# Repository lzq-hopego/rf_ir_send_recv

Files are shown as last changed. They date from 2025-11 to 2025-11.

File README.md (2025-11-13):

## 项目简介
**基于ESP8266的射频和红外网关**
1. 使用ESP8266-12F模组制作射频和红外网关
2. 可对433/315非加密射频信号学习与发送
3. 可对红外信息进行学习和发送
4. 因为作者~~太懒~~(想打造互联生态)所以有了本项目
> 使得以上设备可通过移动端设备进行远程控制

## 打板子注意事项
1. 板厚：**1.2mm**

## 项目架构
```mermaid
graph LR
C{MQTT服务器}
C <-.8083端口.-> D[手机端]
C <-.1883端口.-> E[ESP8266]

```

所有数据围绕着MQTT服务器进行的，因此你需要自己搭建一个MQTT服务器或者使用现成的MQTT服务器
### MQTT服务器架设
> 建议使用docker进行搭建，我们选择**emqx**

```shell
docker run -d --name emqx \
  -p 1883:1883 -p 8083:8083 -p 8084:8084 \
  -p 8883:8883 -p 18083:18083 \
  emqx/emqx-enterprise:latest
```
- 想静静一会就自动部署好啦🎈
- 如果是Linux记得放行端口呦
> EMQX的默认用户名是`admin`,默认密码`public`,web端口默认是`18083`

## 项目功能
> 本项目具有`自学习`，`远程控制`等特点

1. 具有测量实时温湿度功能。
2. 具有433/315信号学习。
3. 具有模拟433/315信号发送。
4. 具有红外信号学习。
5. 具有红外信号发送功能。
6. 具有指示灯。
7. 具有可重置设备的按钮。
8. 具有手机端控制功能。
9. 具有web配网

## 项目方案

1. 使用ESP8266连接路由器后建立MQTT连接实现设备上云。
2. 使用蜂鸟无线 `远-R1`实现433/315信号学习。
3. 使用蜂鸟无线 `远-T1`实现433/315信号发送。
4. 使用`IRM-3638T` 实现红外接收。
5. 使用某宝不知名品牌的`红外发射管` 实现红外发射。
6. 使用`SHT30-DIS-B10KS` 实现实时温湿度测量。

```mermaid
graph LR
C((指示灯))
C -.卡针单戳按钮.-> D[重启 指示灯闪烁2次]
C -.卡针长按按钮.-> E[配置清空 指示灯长亮3次]
C -.接收/发送射频信号.-> F[指示灯短亮1次]
C -.连接上WiFi.-> G[指示灯短亮3次]
```
> 使用手机卡针戳type-c旁的圆孔即可实现上图1、2的操作

## 项目说明
> 简化电路
射频电路参考[RF 433 315射频网关盒子](https://oshwhub.com/yanqisui/rf-433-315-she-pin-wang-guan-he-zi)这个项目，他有说天线的问题
1. 关于天线可以都不焊接，射频接收可直接焊接0欧电阻使用板载天线，射频发射可以直接不焊接任何电阻天线之类的，因为测试过程中生活中的射频接收反而很敏感无需再焊接天线
2. 电路中的type-c旁的`二极管`可以不用焊接直接一坨锡或者0欧电阻或者直接在电路中删去
3. `AMS1117 3.3`后面的钽电容如果想省略也可直接不焊接
4. 电路板左上方的重启按钮也可省略(不是type-c旁边的那个侧贴的按钮，如果不需要物理重置功能也可以删掉，反正WiFi连接失败后会自动让你重新配网)

## 项目源码
1. 手机端APP——uni-app构建      已打包见附件
2. ESP8266端——Arduino          已编译见附件

如果自行编译ESP8266端固件需要修改`PubSubClient`库的`PubSubClient.h`源码
```cpp
#define MQTT_MAX_PACKET_SIZE 4096
```
> 因为我们的很大，它自己默认的太小了，给它~~撑大~~改一点

## 关于外壳
- 外壳是自己画的不太好看，爆炸图效果如下，但是满足嘉立创3D免费打印条件，直接~~白嫖~~免费

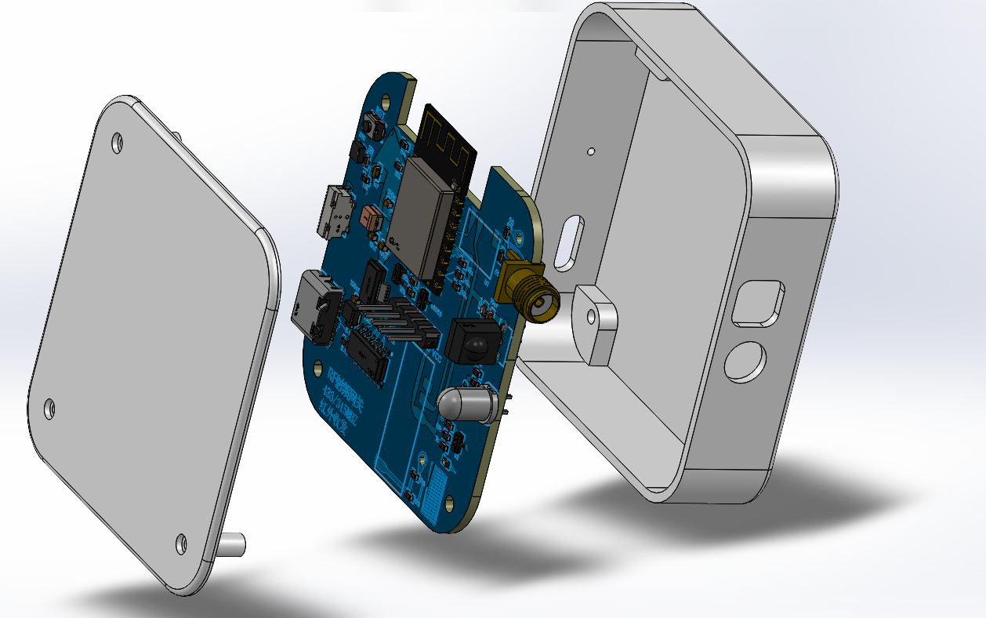
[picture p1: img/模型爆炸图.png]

- 螺丝M1.6*14mm
- 螺母滚花铜螺母M1.6\*3\*2.5

## 效果图
- ESP8266配置页效果图

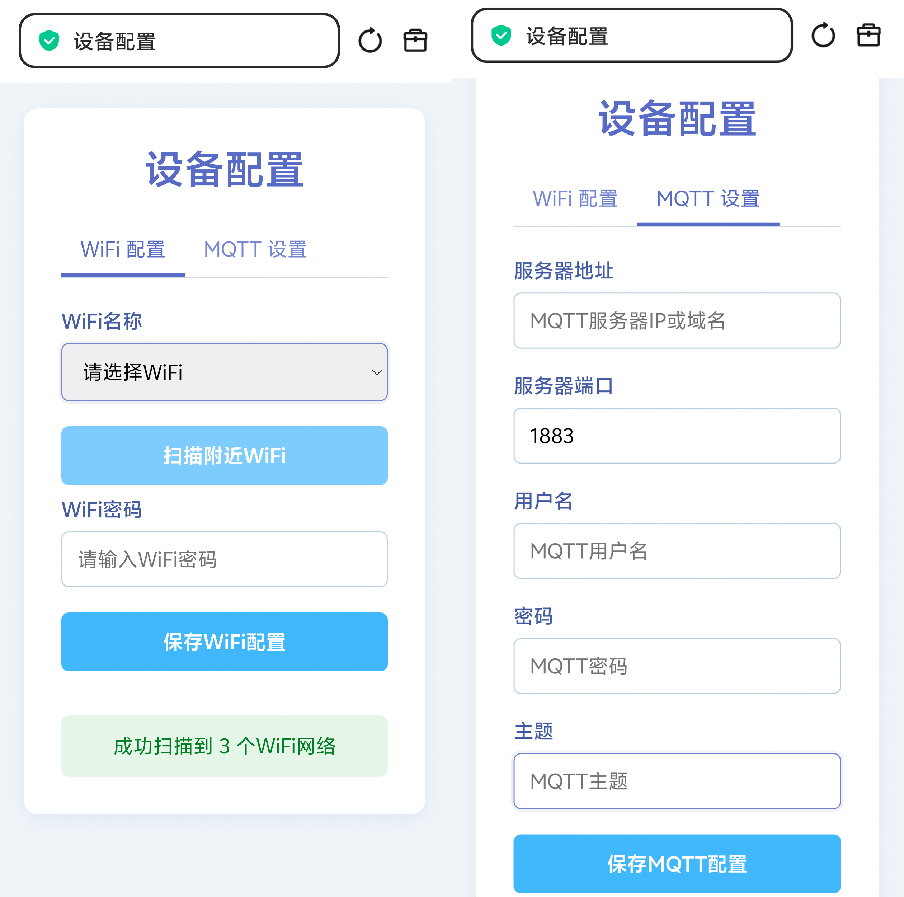
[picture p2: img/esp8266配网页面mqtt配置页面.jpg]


> 这里的服务器端口建议用默认的1883端口，MQTT主题要和软件的主题配置一致，同时建议使用用户名密码方式验证，你可以在EMQX中创建认证数据库时选择这一项

- 手机端效果图

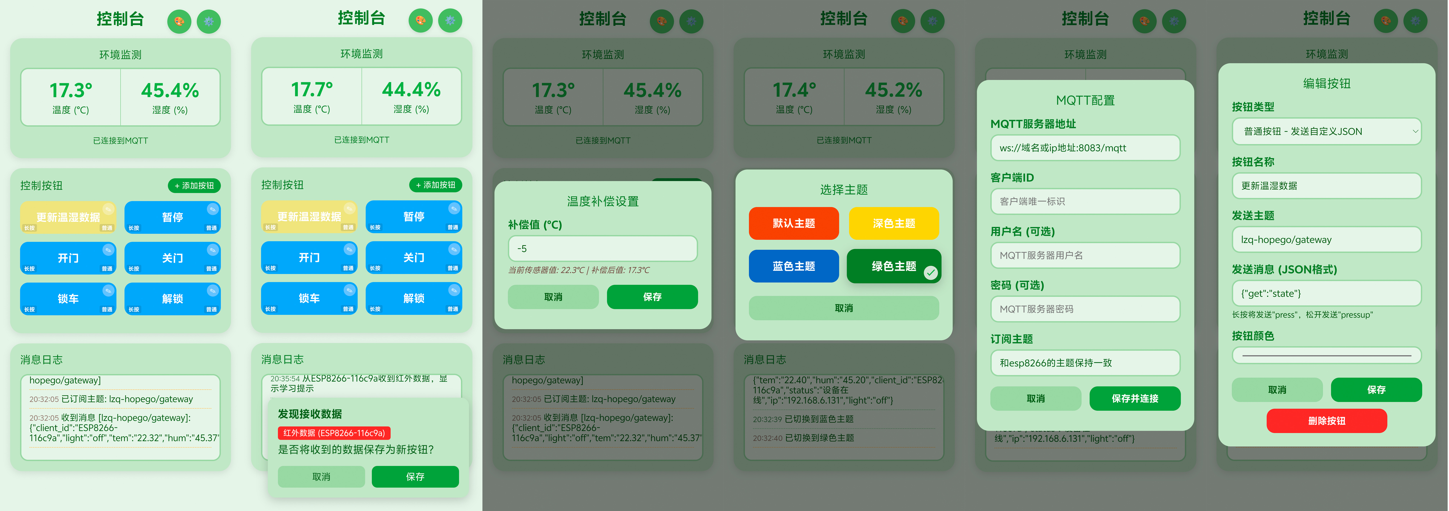
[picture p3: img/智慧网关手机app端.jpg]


> 注意MQTT配置的主题和ESP8266配置的主题一致即可

- 焊接成品图



## 开源声明
1. 本工具仅用于个人学习与研究，禁止任何商业用途（包括但不限于盈利性服务、企业内部使用等）
2. 不得以任何形式任何途径出售本项目提供的固件、软件、以及代码等相关资料
3. 若发现侵权或违规使用情况，请通过维护者邮箱联系，会在 3 个工作日内处理
4. 除去上述要求外，还需遵守本项目的开源协议

## 致谢
> 在以下项目中获得了本项目的灵感
1. [RF 433 315射频网关盒子](https://oshwhub.com/yanqisui/rf-433-315-she-pin-wang-guan-he-zi)
2. [墨水屏阅读器](https://oshwhub.com/jie326513988/SDka-mo-shui-ping-yue-du-qi)
3. [涂鸦_红外](https://oshwhub.com/pppw/tu-ya_-hong-wai)

## 项目信息
- 项目创建者：李先生
- 项目维护者：李先生
- 维护者邮箱：3101978435@qq.com

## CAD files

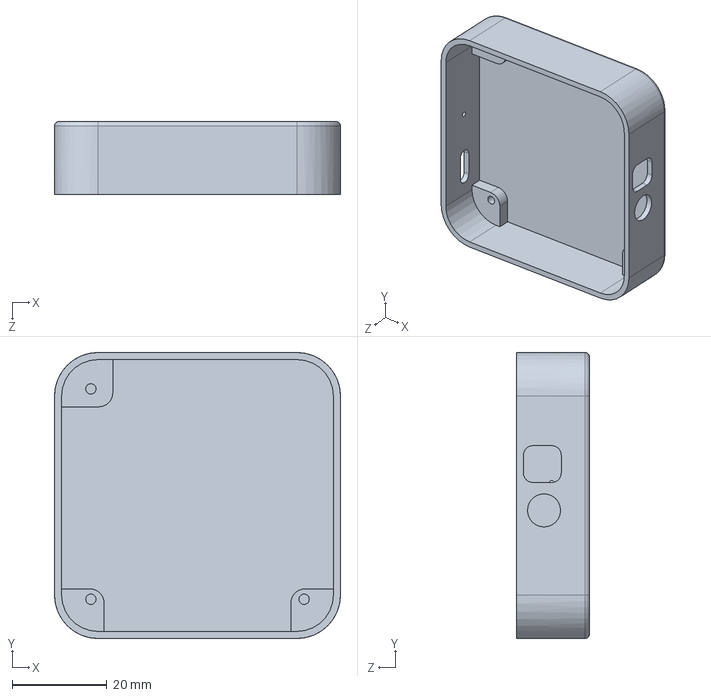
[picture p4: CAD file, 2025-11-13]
3D打印文件/底壳.SLDPRT
60.5 x 60.5 x 15.5 mm

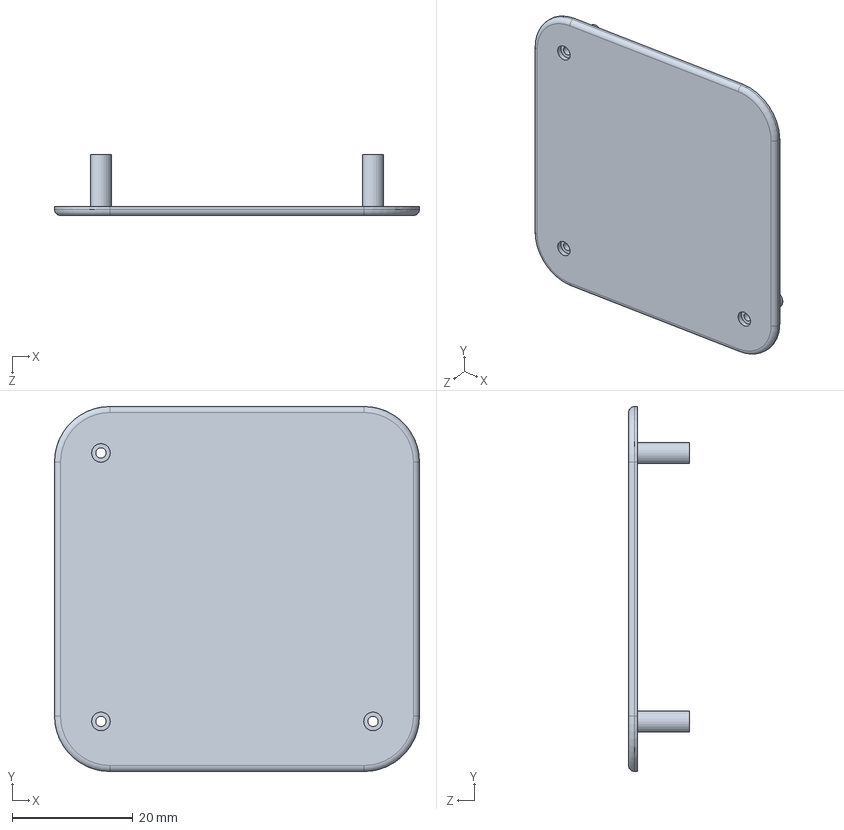
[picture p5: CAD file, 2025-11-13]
3D打印文件/上盖.SLDPRT
60.5 x 60.5 x 10.1 mm

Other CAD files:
3D打印文件/上盖.STL
3D打印文件/底壳.STL

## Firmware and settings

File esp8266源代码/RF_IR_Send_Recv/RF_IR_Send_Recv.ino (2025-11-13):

#include <ESP8266WiFi.h>
#include <ESP8266WebServer.h>
#include <Arduino.h>
#include <EEPROM.h>
#include <ArduinoJson.h>
#include <PubSubClient.h>
#include <RCSwitch.h>
#include <Wire.h>
#include <IRrecv.h>
#include <IRremoteESP8266.h>
#include <IRsend.h>
#include <IRutils.h>
#include "ClosedCube_SHT31D.h"
#include <OneButton.h>  // 引入OneButton库


// 智能网关v1.0.1
// 作者:lzq-hopego
// 最后保存时间:2025年11月12日 21点33分
// 关于代码版权问题，再次开源时需标注原作者，不得商业化，除此之外还需遵守MIT协议


// 配置存储地址和大小
#define EEPROM_SIZE 512
#define CONFIG_ADDR 0          
#define WIFI_ADDR CONFIG_ADDR
#define MQTT_ADDR sizeof(ConfigWiFi)

// 引脚定义（根据硬件调整）
#define BUTTON_PIN 12    // 按钮引脚（一端接IO12，另一端接地）
#define INDICATOR_PIN 15 // 指示灯引脚（高电平点亮）
// 433/315
const int rcsPin = 5; //433发射模块
const int rcrPin = 4; //433接收模块
// 红外接收配置参数
const uint16_t kRecvPin = 0;        // 红外接收引脚（如D3）
const uint32_t kBaudRate = 115200;  // 串口波特率
const uint16_t kCaptureBufferSize = 1024;
const uint8_t kTimeout = 50;        // 信号超时时间（毫秒）
// 红外发射配置参数
const uint16_t kIrLed = D0;

// 全局对象（按钮初始化修改）
RCSwitch mySwitchSend = RCSwitch();
RCSwitch mySwitchRecv = RCSwitch();
ClosedCube_SHT31D sht3xd;
IRrecv irrecv(kRecvPin, kCaptureBufferSize, kTimeout, true);
decode_results results;
IRsend irsend(kIrLed);
// 按钮初始化：禁用内部上拉（因为按钮接GND，按下时为低电平）
OneButton button(BUTTON_PIN);  // 第二个参数改为false（禁用内部上拉）
// 板载LED配置（IO2，低电平点亮）
#define LED_PIN 2
bool ledState = false;  // 记录LED当前状态：false=灭，true=亮

// 配置结构体（保持不变）
struct ConfigWiFi {
  char ssid[32];
  char password[32];
};
struct ConfigMQTT {
  char server[40];
  char port[6];
  char user[32];
  char pass[32];
  char topic[64];
};

// 全局变量（保持不变）
ConfigWiFi configWiFi;
ConfigMQTT configMQTT;
bool mqttUnconfigured = false;  // 控制MQTT未配置提示只显示一次
ESP8266WebServer server(80);
WiFiClient espClient;
PubSubClient mqttClient(espClient);
int reconnectAttempts = 0;
int mqttReconnectAttempts = 0;
String clientId;  // 保存唯一客户端ID用于过滤消息
// AP模式关键参数
const char* apPassword = "12345678";
const int apChannel = 6;
const bool apHidden = false;
const int apMaxConn = 3;
// HTML页面内容（保持不变）
const char index_html[] PROGMEM = R"rawliteral(
<!DOCTYPE html>
<html>
<head>
    <meta charset="UTF-8">
    <meta name="viewport" content="width=device-width, initial-scale=1.0">
    <title>设备配置</title>
    <style>
        * { box-sizing: border-box; margin: 0; padding: 0; }
        body { 
            font-family: 'Arial', sans-serif; 
            max-width: 500px; 
            margin: 0 auto; 
            padding: 20px; 
            background: #f0f4f8; 
            color: #3a4a5c;
        }
        .container { 
            background: white; 
            padding: 30px; 
            border-radius: 12px; 
            box-shadow: 0 4px 15px rgba(100, 120, 180, 0.1);
        }
        h1 { 
            color: #5c6bc0; 
            margin-bottom: 25px; 
            text-align: center;
            font-weight: 600;
        }
        .form-group { 
            margin-bottom: 20px; 
        }
        label { 
            display: block; 
            margin-bottom: 8px; 
            font-weight: 500;
            color: #4a5ca0;
        }
        input, select { 
            width: 100%; 
            padding: 12px; 
            border: 1px solid #bdd0e0; 
            border-radius: 6px; 
            font-size: 16px;
            transition: border 0.3s;
        }
        input:focus, select:focus { 
            border-color: #7986cb; 
            outline: none; 
            box-shadow: 0 0 0 2px rgba(100, 120, 180, 0.1);
        }
        button { 
            width: 100%; 
            padding: 14px; 
            background: #64b5f6; 
            color: white; 
            border: none; 
            border-radius: 6px; 
            font-size: 16px; 
            font-weight: 600; 
            cursor: pointer;
            transition: background 0.3s;
            margin-bottom: 15px;
        }
        button:hover { 
            background: #42a5f5; 
        }
        .scan-btn {
            background: #90caf9;
            margin-bottom: 10px;
        }
        .scan-btn:hover {
            background: #64b5f6;
        }
        .status {
            margin-top: 20px;
            padding: 15px;
            border-radius: 6px;
            display: none;
            text-align: center;
        }
        .success {
            background: #e8f5e9;
            color: #2e7d32;
            display: block;
        }
        .error {
            background: #ffebee;
            color: #c62828;
            display: block;
        }
        .tab-content {
            display: none;
        }
        .tab-content.active {
            display: block;
        }
        .nav-tabs {
            display: flex;
            margin-bottom: 25px;
            border-bottom: 1px solid #d1d9e6;
        }
        .nav-tab {
            padding: 10px 15px;
            cursor: pointer;
            color: #7986cb;
            border-bottom: 3px solid transparent;
            transition: all 0.3s;
        }
        .nav-tab.active {
            color: #5c6bc0;
            border-bottom: 3px solid #5c6bc0;
        }
        .nav-tab:hover {
            color: #5c6bc0;
        }
        .loading {
            text-align: center;
            color: #5c6bc0;
            padding: 10px;
            display: none;
        }
    </style>
</head>
<body>
    <div class="container">
        <h1>设备配置</h1>
        <div class="nav-tabs">
            <div class="nav-tab active" onclick="showTab('wifi-tab')">WiFi 配置</div>
            <div class="nav-tab" onclick="showTab('mqtt-tab')">MQTT 设置</div>
        </div>
        <div id="wifi-tab" class="tab-content active">
            <div class="form-group">
                <label for="ssid">WiFi名称</label>
                <select id="ssid" required>
                    <option value="">请选择WiFi</option>
                </select>
            </div>
            <button class="scan-btn" onclick="scanWiFi()">扫描附近WiFi</button>
            <div class="loading" id="wifi-loading">正在扫描WiFi...</div>
            <div class="form-group">
                <label for="wifi_password">WiFi密码</label>
                <input type="password" id="wifi_password" placeholder="请输入WiFi密码">
            </div>
            <button onclick="saveWiFiConfig()">保存WiFi配置</button>
        </div>
        <div id="mqtt-tab" class="tab-content">
            <div class="form-group">
                <label for="mqtt_server">服务器地址</label>
                <input type="text" id="mqtt_server" placeholder="MQTT服务器IP或域名" required>
            </div>
            <div class="form-group">
                <label for="mqtt_port">服务器端口</label>
                <input type="number" id="mqtt_port" value="1883" required>
            </div>
            <div class="form-group">
                <label for="mqtt_user">用户名</label>
                <input type="text" id="mqtt_user" placeholder="MQTT用户名">
            </div>
            <div class="form-group">
                <label for="mqtt_pass">密码</label>
                <input type="password" id="mqtt_pass" placeholder="MQTT密码">
            </div>
            <div class="form-group">
                <label for="mqtt_topic">主题</label>
                <input type="text" id="mqtt_topic" placeholder="MQTT主题" required>
            </div>
            <button onclick="saveMQTTConfig()">保存MQTT配置</button>
        </div>
        <div id="status" class="status"></div>
    </div>
    <script>
        function showTab(tabId) {
            document.querySelectorAll('.tab-content').forEach(tab => tab.classList.remove('active'));
            document.querySelectorAll('.nav-tab').forEach(nav => nav.classList.remove('active'));
            document.getElementById(tabId).classList.add('active');
            document.querySelector(`.nav-tab[onclick="showTab('${tabId}')"]`).classList.add('active');
        }
        function scanWiFi() {
          document.getElementById('wifi-loading').style.display = 'block';
          fetch('/scanWiFi')
            .then(response => {
              if (!response.ok) {
                throw new Error(`HTTP错误：${response.status}`);
              }
              return response.json();
            })
            .then(networks => {
              const ssidSelect = document.getElementById('ssid');
              while (ssidSelect.options.length > 1) {
                ssidSelect.remove(1);
              }
              if (networks.length === 0) {
                showStatus('未发现可用WiFi网络', 'error');
                return;
              }
              networks.sort((a, b) => b.rssi - a.rssi);
              networks.forEach(network => {
                const option = document.createElement('option');
                option.value = network.ssid;
                const signal = Math.min(100, Math.max(0, (network.rssi + 100) * 2));
                option.textContent = `${network.ssid} (信号: ${signal}%)`;
                ssidSelect.appendChild(option);
              });
              showStatus(`成功扫描到 ${networks.length} 个WiFi网络`, 'success');
            })
            .catch(error => {
              showStatus(`WiFi扫描失败：${error.message}`, 'error');
              console.error('扫描错误详情：', error);
            })
            .finally(() => {
              document.getElementById('wifi-loading').style.display = 'none';
            });
        }
        function saveWiFiConfig() {
            const config = {
                ssid: document.getElementById('ssid').value,
                password: document.getElementById('wifi_password').value
            };
            fetch('/saveWiFiConfig', {
                method: 'POST',
                headers: { 'Content-Type': 'application/json' },
                body: JSON.stringify(config)
            })
            .then(response => response.text())
            .then(data => {
                showStatus(data, data.includes('成功') ? 'success' : 'error');
                if (data.includes('成功')) {
                    setTimeout(() => window.location.href = '/', 2000);
                }
            })
            .catch(error => showStatus('WiFi配置保存失败', 'error'));
        }
        function saveMQTTConfig() {
            const config = {
                server: document.getElementById('mqtt_server').value,
                port: document.getElementById('mqtt_port').value,
                user: document.getElementById('mqtt_user').value,
                pass: document.getElementById('mqtt_pass').value,
                topic: document.getElementById('mqtt_topic').value
            };
            fetch('/saveMQTTConfig', {
                method: 'POST',
                headers: { 'Content-Type': 'application/json' },
                body: JSON.stringify(config)
            })
            .then(response => response.text())
            .then(data => {
                showStatus(data, data.includes('成功') ? 'success' : 'error');
                if (data.includes('成功')) {
                    setTimeout(() => window.location.href = '/', 2000);
                }
            })
            .catch(error => showStatus('MQTT配置保存失败', 'error'));
        }
        function showStatus(message, type) {
            const statusEl = document.getElementById('status');
            statusEl.textContent = message;
            statusEl.className = `status ${type}`;
        }
        window.onload = function() {
            fetch('/getWiFiConfig')
                .then(response => response.json())
                .then(config => {
                    if (config.ssid) {
                        const ssidSelect = document.getElementById('ssid');
                        let hasOption = false;
                        for (let i = 0; i < ssidSelect.options.length; i++) {
                            if (ssidSelect.options[i].value === config.ssid) {
                                ssidSelect.selectedIndex = i;
                                hasOption = true;
                                break;
                            }
                        }
                        if (!hasOption) {
                            const option = document.createElement('option');
                            option.value = config.ssid;
                            option.textContent = config.ssid;
                            option.selected = true;
                            ssidSelect.appendChild(option);
                        }
                    }
                });
            fetch('/getMQTTConfig')
                .then(response => response.json())
                .then(config => {
                    if (config.server) document.getElementById('mqtt_server').value = config.server;
                    if (config.port) document.getElementById('mqtt_port').value = config.port;
                    if (config.user) document.getElementById('mqtt_user').value = config.user;
                    if (config.topic) document.getElementById('mqtt_topic').value = config.topic;
                });
        }
    </script>
</body>
</html>
)rawliteral";

// 指示灯控制函数（高电平点亮）
#line 386 "E:\\Arduino_program\\IRsendDemo\\IRsendDemo.ino"
void publishWithClientId(const char* content);
#line 396 "E:\\Arduino_program\\IRsendDemo\\IRsendDemo.ino"
bool connectMQTT();
#line 441 "E:\\Arduino_program\\IRsendDemo\\IRsendDemo.ino"
void onButtonClick();
#line 449 "E:\\Arduino_program\\IRsendDemo\\IRsendDemo.ino"
void onButtonLongPress();
#line 470 "E:\\Arduino_program\\IRsendDemo\\IRsendDemo.ino"
void mqttCallback(char* topic, byte* payload, unsigned int length);
#line 603 "E:\\Arduino_program\\IRsendDemo\\IRsendDemo.ino"
void initEEPROM();
#line 622 "E:\\Arduino_program\\IRsendDemo\\IRsendDemo.ino"
void saveWiFiToEEPROM();
#line 628 "E:\\Arduino_program\\IRsendDemo\\IRsendDemo.ino"
void saveMQTTToEEPROM();
#line 634 "E:\\Arduino_program\\IRsendDemo\\IRsendDemo.ino"
void clearWiFiConfig();
#line 642 "E:\\Arduino_program\\IRsendDemo\\IRsendDemo.ino"
void startAP();
#line 652 "E:\\Arduino_program\\IRsendDemo\\IRsendDemo.ino"
bool connectWiFi();
#line 693 "E:\\Arduino_program\\IRsendDemo\\IRsendDemo.ino"
void scanWiFiNetworks();
#line 722 "E:\\Arduino_program\\IRsendDemo\\IRsendDemo.ino"
void handleRoot();
#line 723 "E:\\Arduino_program\\IRsendDemo\\IRsendDemo.ino"
void handleGetWiFiConfig();
#line 730 "E:\\Arduino_program\\IRsendDemo\\IRsendDemo.ino"
void handleGetMQTTConfig();
#line 740 "E:\\Arduino_program\\IRsendDemo\\IRsendDemo.ino"
void handleSaveWiFiConfig();
#line 758 "E:\\Arduino_program\\IRsendDemo\\IRsendDemo.ino"
void handleSaveMQTTConfig();
#line 782 "E:\\Arduino_program\\IRsendDemo\\IRsendDemo.ino"
void setup();
#line 833 "E:\\Arduino_program\\IRsendDemo\\IRsendDemo.ino"
void loop();
#line 376 "E:\\Arduino_program\\IRsendDemo\\IRsendDemo.ino"
void indicatorLight(int times = 1, int duration = 100) {
  for (int i = 0; i < times; i++) {
    digitalWrite(INDICATOR_PIN, HIGH);  // 高电平点亮指示灯（适配你的硬件）
    delay(duration);
    digitalWrite(INDICATOR_PIN, LOW);   // 低电平熄灭
    if (i < times - 1) delay(duration); // 多次闪烁时的间隔
  }
}

// 新增：带客户端ID的消息发布函数
void publishWithClientId(const char* content) {
  StaticJsonDocument<256> doc;
  doc["client_id"] = clientId;  // 附加客户端ID
  doc["content"] = content;     // 消息内容
  String json;
  serializeJson(doc, json);
  mqttClient.publish(configMQTT.topic, json.c_str());
}

// MQTT连接函数（修改：初始化客户端ID）
bool connectMQTT() {
  if (strlen(configMQTT.server) == 0) {
    if (!mqttUnconfigured) {
      Serial.println("MQTT服务器未配置，跳过连接");
      mqttUnconfigured = true;  // 已提示过，后续不再提示
    }
    return false;
  }
  // 初始化唯一客户端ID（基于芯片ID）
  clientId = "ESP8266-" + String(ESP.getChipId(), HEX);
  mqttClient.setServer(configMQTT.server, atoi(configMQTT.port));
  Serial.print("连接MQTT服务器: ");
  Serial.print(configMQTT.server);
  Serial.print(":");
  Serial.println(configMQTT.port);
  
  if (mqttClient.connect(
    clientId.c_str(), 
    configMQTT.user,
    configMQTT.pass,
    configMQTT.topic,
    0, 1,
    "设备离线"
  )) {
    Serial.println("MQTT连接成功");
    Serial.print("客户端ID: ");
    Serial.println(clientId);
    mqttReconnectAttempts = 0;
    if (mqttClient.subscribe(configMQTT.topic)) {
      Serial.print("已订阅主题: ");
      Serial.println(configMQTT.topic);
    } else {
      Serial.print("订阅主题失败: ");
      Serial.println(configMQTT.topic);
    }
    return true;
  } else {
    Serial.print("MQTT连接失败，错误代码: ");
    Serial.println(mqttClient.state());
    mqttReconnectAttempts++;
    return false;
  }
}

// 按钮单击事件：重启设备（保持逻辑不变）
void onButtonClick() {
  Serial.println("检测到按钮单击，准备重启设备...");
  indicatorLight(2);  // 闪烁2次表示即将重启
  delay(1000);
  ESP.restart();
}

// 按钮长按事件：清空配置并重新配网（保持逻辑不变）
void onButtonLongPress() {
  Serial.println("检测到按钮长按，准备清空配置...");
  // 清空WiFi配置
  strcpy(configWiFi.ssid, "");
  strcpy(configWiFi.password, "");
  saveWiFiToEEPROM();
  // 清空MQTT配置
  strcpy(configMQTT.server, "");
  strcpy(configMQTT.port, "1883");
  strcpy(configMQTT.user, "");
  strcpy(configMQTT.pass, "");
  strcpy(configMQTT.topic, "");
  saveMQTTToEEPROM();
  
  indicatorLight(3, 300);  // 长亮3次表示配置已清空
  Serial.println("配置已清空，重启进入配网模式");
  delay(1000);
  ESP.restart();
}
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
void loop() {
  server.handleClient();  // 处理Web请求
  button.tick();          // 按钮状态检测（必须放在loop中）
  
  // 红外接收
  if (irrecv.decode(&results)) {
    Serial.println("\n--- 检测到红外信号 ---");
    // 输出原始数据
    String irData = resultToSourceCode(&results);
    Serial.print("原始数据: ");
    Serial.println(irData);
    // 提取原始数据数组中的数值部分（仅保留{}内的内容）
    int startIdx = irData.indexOf("{") + 1;  // 找到{的位置并+1
    int endIdx = irData.lastIndexOf("}");     // 找到}的位置
    String irValues = irData.substring(startIdx, endIdx);  // 提取中间的数值部分
    
    // 仅在MQTT连接时发布红外数据
    if (mqttClient.connected()) {
      StaticJsonDocument<1024> statusDoc;
      statusDoc["client_id"] = clientId;
      statusDoc["ir_receive"] = irValues;  // 红外接收数据
      String statusJson;
      serializeJson(statusDoc, statusJson);
      
      if (mqttClient.publish(configMQTT.topic, statusJson.c_str())) {
        Serial.println("红外数据已发布: " + statusJson);
      } else {
        Serial.println("红外数据发布失败");
      }
    } else {
      Serial.println("MQTT未连接，红外数据暂不发布");
    }
    
    irrecv.resume();  // 继续接收下一个信号
  }


  // 433接收逻辑
  if (mySwitchRecv.available()) {
    long receivedValue = mySwitchRecv.getReceivedValue();
    if (receivedValue != 0) {
      Serial.print("收到射频数据: ");
      Serial.println(receivedValue);
      indicatorLight();  // 433接收成功，指示灯闪一下

      // 仅在MQTT连接时发布数据
      if (mqttClient.connected()) {
        StaticJsonDocument<128> statusDoc;
        statusDoc["client_id"] = clientId;
        statusDoc["rf_receive"] = receivedValue;
        String statusJson;
        serializeJson(statusDoc, statusJson);
        
        if (mqttClient.publish(configMQTT.topic, statusJson.c_str())) {
          Serial.println("射频数据已发布: " + statusJson);
        } else {
          Serial.println("射频数据发布失败");
        }
      } else {
        Serial.println("MQTT未连接，射频数据暂不发布");
      }
    }
    mySwitchRecv.resetAvailable();  // 重置接收状态
  }
  
  // WiFi重连逻辑
  if (WiFi.status() != WL_CONNECTED) {
    if (strlen(configWiFi.ssid) > 0) {
      Serial.print("WiFi重连(");
      Serial.print(reconnectAttempts + 1);
      Serial.println(")...");
      if (!connectWiFi() && reconnectAttempts >= 3) {
        clearWiFiConfig();
        ESP.restart();
      }
    }
    delay(5000);
    return;
  }
  
  // MQTT重连逻辑
  if (!mqttClient.connected()) {
    if (mqttReconnectAttempts < 5) {
      connectMQTT();
    } else {
      Serial.println("MQTT重连次数过多，等待30秒...");
      delay(30000);
      mqttReconnectAttempts = 0;
    }
  } else {
    mqttClient.loop();
    
    // 定时发布在线状态（30秒一次）
    static unsigned long lastPublish = 0;
    if (millis() - lastPublish > 30000) {
      StaticJsonDocument<128> statusDoc;
      SHT31D sht_result=sht3xd.periodicFetchData();
      if (sht_result.error == SHT3XD_NO_ERROR) {
        statusDoc["tem"]=String(sht_result.t, 2);
        statusDoc["hum"]=String(sht_result.rh, 2);
      }else{
        Serial.print("SHT30: 读取失败，错误代码=");
        Serial.println(sht_result.error);
      }
      statusDoc["client_id"] = clientId;
      statusDoc["status"] = "设备在线";
      statusDoc["ip"] = WiFi.localIP().toString();
      statusDoc["light"] = ledState ? "on" : "off";
      String statusJson;
      serializeJson(statusDoc, statusJson);
      
      if (mqttClient.publish(configMQTT.topic, statusJson.c_str())) {
        Serial.println("发布状态成功: " + statusJson);
      } else {
        Serial.println("发布状态失败");
      }
      lastPublish = millis();
    }
  }
  
  delay(50);
}
